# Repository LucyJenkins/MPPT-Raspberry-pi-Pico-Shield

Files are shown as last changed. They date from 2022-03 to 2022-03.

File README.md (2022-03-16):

# MPPT-Raspberry-pi-Pico-Shield
A small project implementing a Maximum Power Point Tracker using the format of Raspberry pi Pico Shield

# References:
1. https://fr.scribd.com/document/404356941/Regulated-Output-Voltage-Double-Switch-Buck-Boost-Converter-for-Photovoltaic-Energy-Application 
2. https://www.engr.colostate.edu/ECE562/98lectures/l09.pdf

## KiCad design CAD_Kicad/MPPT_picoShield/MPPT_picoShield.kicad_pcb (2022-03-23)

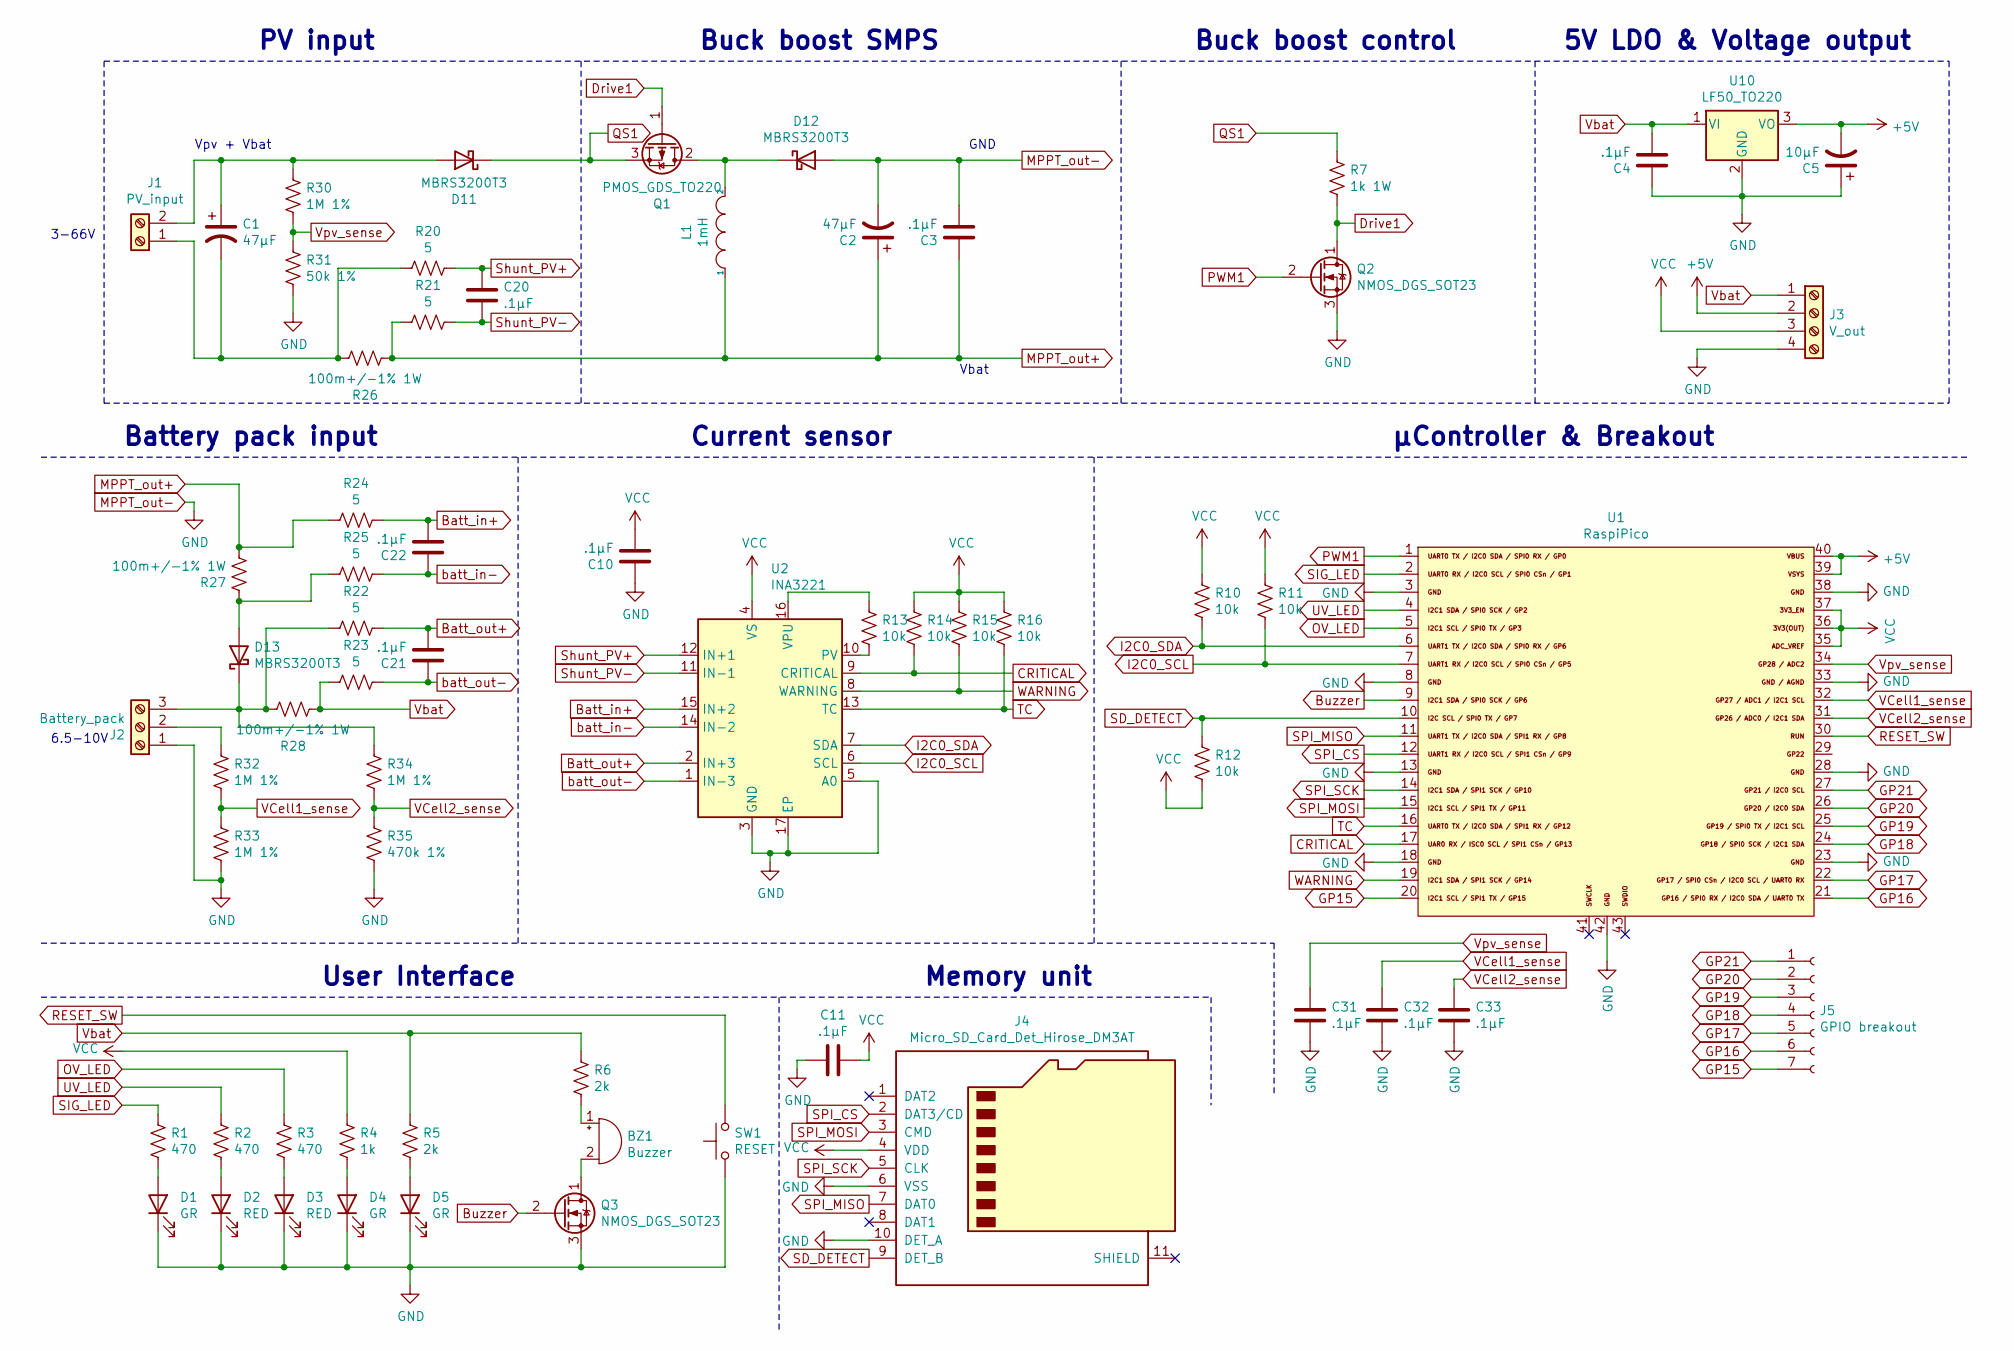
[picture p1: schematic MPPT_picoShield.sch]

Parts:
BZ1: Buzzer; PKM13EPYH4002-B0
C1, C2: 47µF; CP_Radial_D10.0mm_P5.00mm
C3, C4, C10, C11, C20, C21, C22, C31, C32, C33: .1µF; C_0603_1608Metric
C5: 10µF; CP_Radial_D10.0mm_P5.00mm
D1, D4, D5: GR; LED_0805_2012Metric
D2, D3: RED; LED_0805_2012Metric
D11, D12, D13: MBRS3200T3; MBRS3200T3G
J1: PV_input; TerminalBlock_bornier-2_P5.08mm
J2: Battery_pack; TerminalBlock_bornier-3_P5.08mm
J3: V_out; TerminalBlock_bornier-4_P5.08mm
J4: Micro_SD_Card_Det_Hirose_DM3AT; DM3ATSFPEJM5
J5: GPIO breakout; PinHeader_1x07_P2.54mm_Vertical
L1: 1mH; PA4320.105NLT
Q1: PMOS_GDS_TO220; TO-220-3_Vertical
Q2, Q3: NMOS_DGS_SOT23; SOT-23
R1, R2, R3: 470; R_0603_1608Metric
R4: 1k; R_0603_1608Metric
R5, R6: 2k; R_0603_1608Metric
R7: 1k 1W; R_1206_3216Metric
R10, R11, R12, R13, R14, R15, R16: 10k; R_0603_1608Metric
R20, R21, R22, R23, R24, R25: 5; R_0603_1608Metric
R26, R27, R28: 100m+/-1% 1W; R_1206_3216Metric
R30, R32, R33, R34: 1M 1%; R_0603_1608Metric
R31: 50k 1%; R_0603_1608Metric
R35: 470k 1%; R_0603_1608Metric
SW1: RESET; SW_PUSH_6mm
U1: RaspiPico
U2: INA3221; Texas_RGV_S-PVQFN-N16_EP2.1x2.1mm
U10: LF50_TO220; TO-220-3_Vertical

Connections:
+5V: C5.2, J3.2, U1.39, U1.40, U10.3 (VO)
Batt_in+: C22.2, R24.1, U2.15 (IN+2)
Batt_out+: C21.2, R22.1, U2.2 (IN+3)
Buzzer: Q3.2 (G), U1.9
CRITICAL: R14.2, U1.17, U2.9 (CRITICAL)
Drive1: Q1.1 (G), Q2.1 (D), R7.2
GP15: J5.7, U1.20
GP16: J5.6, U1.21
GP17: J5.5, U1.22
GP18: J5.4, U1.24
GP19: J5.3, U1.25
GP20: J5.2, U1.26
GP21: J5.1, U1.27
I2C0_SCL: R11.2, U1.7, U2.6 (SCL)
I2C0_SDA: R10.2, U1.6, U2.7 (SDA)
MPPT_out+: C2.1, C3.1, L1.1, R21.2, R24.2, R26.2, R27.2; also elsewhere on the board
MPPT_out-: C2.2, C3.2, C4.1, C5.1, C10.1, C11.2, C31.2, C32.2, C33.2, D1.1 (K), D2.1 (K), D3.1 (K), D4.1 (K), D5.1 (K), D12.2 (A), J2.1, J3.4, J4.6 (VSS), J4.10 (DET_A), Q2.3 (S), Q3.3 (S), R31.2, R33.2, R35.2, SW1.1, U1.3, U1.8, U1.13, U1.18, U1.23, U1.28, U1.33, U1.38, U1.42, U2.3 (GND), U2.5 (A0), U2.17 (EP), U10.2 (GND); also elsewhere on the board
unnamed: BZ1.1 (-), R6.2
unnamed: BZ1.2 (+), Q3.1 (D)
unnamed 19: C1.1, D11.2 (A), J1.2, R30.1; also elsewhere on the board
unnamed 20: C1.2, J1.1, R20.2, R26.1; also elsewhere on the board
unnamed: D1.2 (A), R1.2
unnamed: D2.2 (A), R2.2
unnamed: D3.2 (A), R3.2
unnamed: D4.2 (A), R4.2
unnamed: D5.2 (A), R5.2
unnamed 26: D12.1 (K), L1.2, Q1.2 (D); also elsewhere on the board
unnamed: D13.1 (K), J2.3, R22.2, R28.1, R34.1
unnamed: D13.2 (A), R25.2, R27.1
unnamed: J2.2, R32.1
unnamed: R13.1, U2.16 (VPU)
unnamed: R13.2, U2.10 (PV)
OV_LED: R3.1, U1.5
PWM1: Q2.2 (G), U1.1
QS1: D11.1 (K), Q1.3 (S), R7.1
RESET_SW: SW1.2, U1.30
SD_DETECT: J4.9 (DET_B), R12.1, U1.10
SIG_LED: R1.1, U1.2
SPI_CS: J4.2 (DAT3/CD), U1.12
SPI_MISO: J4.7 (DAT0), U1.11
SPI_MOSI: J4.3 (CMD), U1.15
SPI_SCK: J4.5 (CLK), U1.14
Shunt_PV+: C20.1, R20.1, U2.12 (IN+1)
Shunt_PV-: C20.2, R21.1, U2.11 (IN-1)
TC: R16.2, U1.16, U2.13 (TC)
UV_LED: R2.1, U1.4
VCC: C10.2, C11.1, J3.3, J4.4 (VDD), R4.1, R10.1, R11.1, R12.2, R14.1, R15.1, R16.1, U1.35, U1.36, U1.37, U2.4 (VS); also elsewhere on the board
VCell1_sense: C32.1, R32.2, R33.1, U1.32
VCell2_sense: C33.1, R34.2, R35.1, U1.31
Vbat: C4.2, J3.1, R5.1, R6.1, R23.2, R28.2, U10.1 (VI); also elsewhere on the board
Vpv_sense: C31.1, R30.2, R31.1, U1.34
WARNING: R15.2, U1.19, U2.8 (WARNING)
batt_in-: C22.1, R25.1, U2.14 (IN-2)
batt_out-: C21.1, R23.1, U2.1 (IN-3)

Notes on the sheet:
Vpv + Vbat
Vbat
GND
Buck boost SMPS
PV input
Battery pack input
Buck boost control
µController & Breakout
User Interface
Memory unit
5V LDO & Voltage output
Current sensor
3-66V
6.5-10V

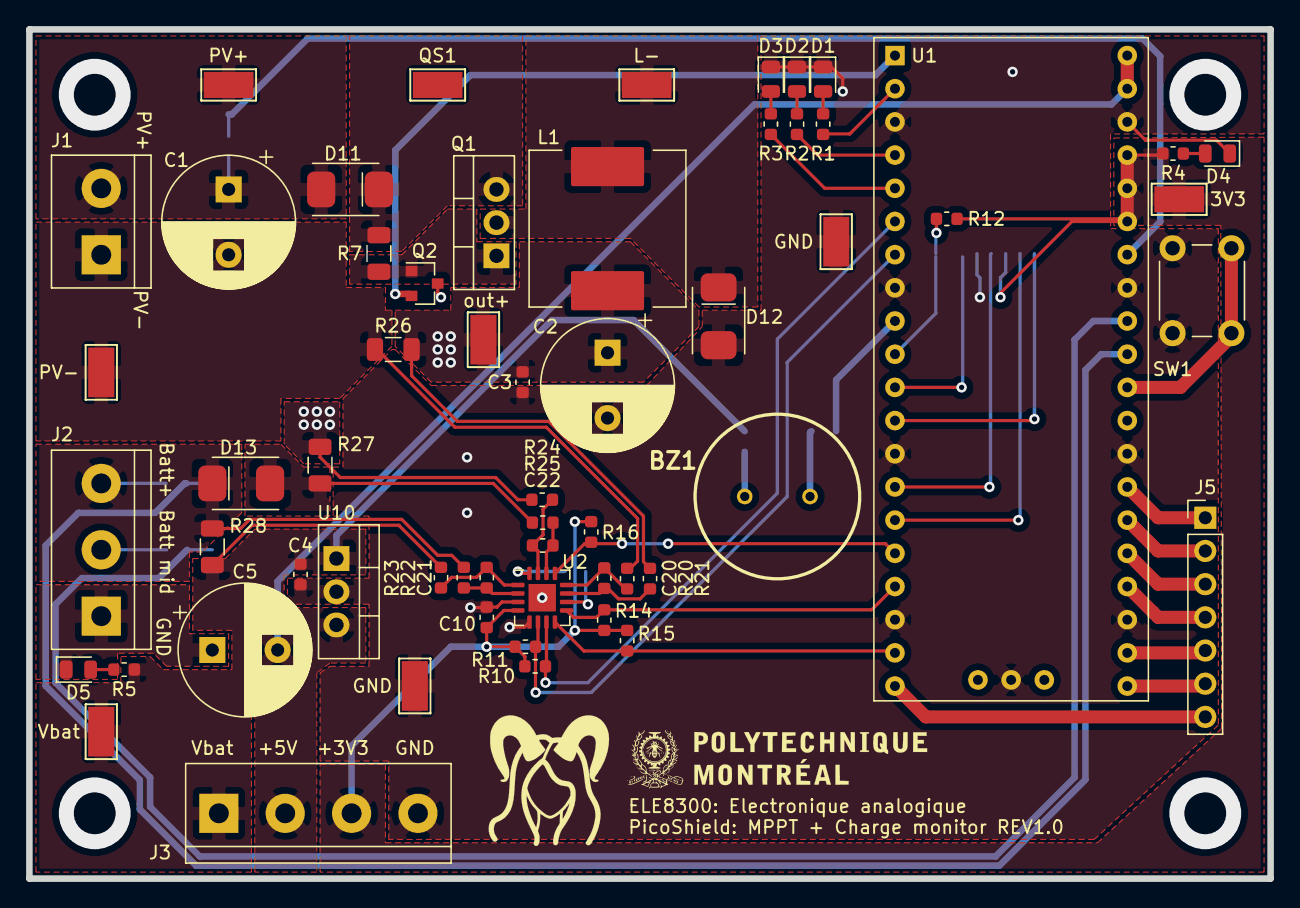
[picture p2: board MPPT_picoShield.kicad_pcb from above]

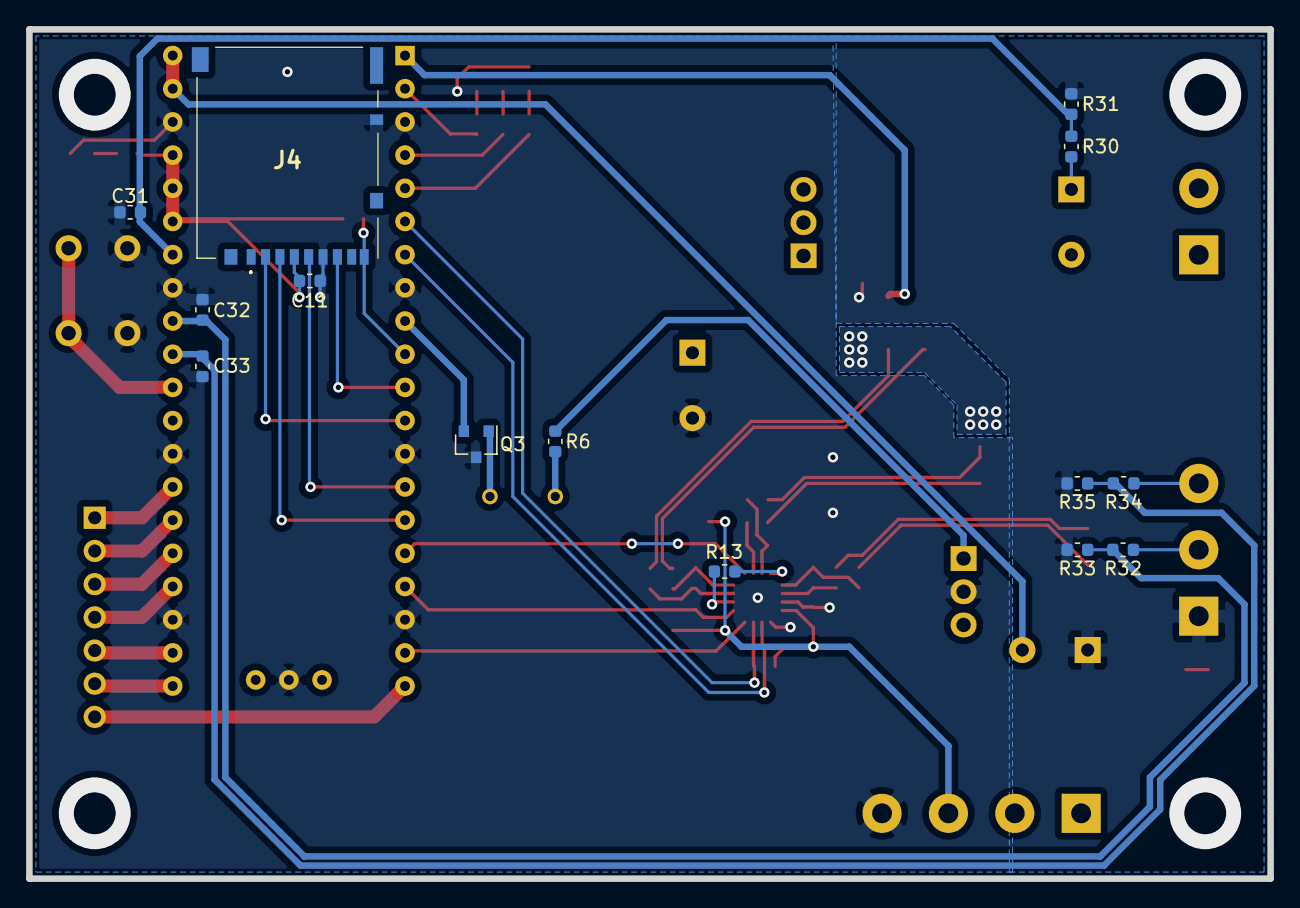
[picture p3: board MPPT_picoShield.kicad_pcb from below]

Board: 2 copper layers, 95.0 x 65.0 mm, 73 parts (14 on the bottom side), 54 nets.

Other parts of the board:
3V3: TestPoint_Keystone_5019_Minature
GND: TestPoint_Keystone_5019_Minature
GND#2: TestPoint_Keystone_5019_Minature
L-: TestPoint_Keystone_5019_Minature
PV+: TestPoint_Keystone_5019_Minature
PV-: TestPoint_Keystone_5019_Minature
QS1: TestPoint_Keystone_5019_Minature
Vbat: TestPoint_Keystone_5019_Minature
out+: TestPoint_Keystone_5019_Minature

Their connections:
MPPT_out+: out+.1; also elsewhere on the board
MPPT_out-: GND.1, GND#2.1; also elsewhere on the board
unnamed 19: PV+.1; also elsewhere on the board
unnamed 20: PV-.1; also elsewhere on the board
unnamed 26: L-.1; also elsewhere on the board
VCC: 3V3.1; also elsewhere on the board
Vbat: Vbat.1; also elsewhere on the board

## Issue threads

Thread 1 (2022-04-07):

Python logic core cannot follow fast decreasing power level

LucyJenkins, 2022-04-07:
Small grammar mistake to be corrected (missing ':')

If the power level of the solar panel decreases too rapidly, the MPPT algorithm cannot correctly follow the power point and will let the current fall down to zero. This can lead to a lockout wherein the system does not recover.

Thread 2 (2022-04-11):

Hardware issues on REV1.0

LucyJenkins, 2022-04-11:
Spotted hardware issues to improve on in next revision:

1. Pin 3V3_EN of raspberry pico must not be set to 3V3 (this state does not count as high)
2. N mos transistors have to be switched to the standard GDS pinout (for ease of supplying)
3. Diode D13 may not be correctly polarized if solar panel power is too low - this diode may be removable, option should be explored to reduce complexity
4. Use of resistive voltage dividers to measure voltages seems unsatisfactory and hard to tune - next revision should use specialized hardware. This could also reduce the length of analog lines

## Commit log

2022-03-15 Add files via upload
    Initial commit of hardware schematic - basic architecture layed - has to be finished
    [MPPT_picoShield.kicad_pcb, MPPT_picoShield.sch]
2022-03-16 Finished electrical schematic - pending review
    Final decisions on component choices have to be made, special attention should be put towards the microSD card (there seems to be a conflict between electrical schematic and footprint gathered on the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
    [MPPT_picoShield.sch]
2022-03-17 Initial placement of components on PCB board
    Initial placement - issue spotted on shunt resistors: hard to route because of crossing, pending solution
    [MPPT_picoShield.sch]
2022-03-18 Initial routing
    Small verifications to be made:
    - Should Metal of INA2331 be connected to ground? Or a floating metal plane? or Vcc?
    - Should capacitors be added to the long analog lines to stabilize them?
    - Should D11 and its polarized cap be swapped to "idiot proof" the PV connector?
    - Rasp Pico silkscreen is outside of PCB, should probably fix that
    - Indicator of pin 1 on INA2331 is overlapping a via, small esthetic fix to be made
    - Note for future: DPAK or TO220?
    [MPPT_picoShield.kicad_pcb, MPPT_picoShield.sch]
2022-03-23 Small Changes for hardware "correctability" reasons
    Added testpoints
    Changed rooting around INA to solve the thermal pad to ground uncertainty. Now able to solve this using an exacto blade
    Added PolyMTL logo
    [MPPT_picoShield.kicad_pcb]
2022-03-23 Gerber gen and added filtering caps on ADC lines
    [MPPT_picoShield-B_Cu.gbr, MPPT_picoShield-B_Mask.gbr, MPPT_picoShield-B_Paste.gbr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]
2022-04-07 Logic and sim update
    Fixed python grammar issue
    Added logic to search a working power point if no power is seen (cycle through all duty cycles with a ramp until a working point can be found)
    Updated simulation logic to allow for tracking tests using a sinusoidal power on solar panel. Updated simulation logic to prevent negative current generation (exponent of exponential greater than 0)
2022-04-08 Logic refactor and improvement
    Target of the application is to charge a battery => The input current of the battery pack is the most important variable of the system. We thus try to follow the desired intensity with the buck boost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
    Pending further readability improvements (may delete unused sections)
2022-04-11 Logic & sim feedback improvements
    Logic improvements include:
    - mapping of available currents to quickly converge to a solution (tries to mitigate the local maximum problem)
    Sim improvements include:
    - brute forcing for the best solution at every simulation point
    - ouput of those point in the .csv output of the script
    Readability improvements include
    - Provided a matlab script to display simulation results
    - Clean up of code to remove cluter code
